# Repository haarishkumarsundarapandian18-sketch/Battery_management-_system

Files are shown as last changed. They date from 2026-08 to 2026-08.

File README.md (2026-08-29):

# Battery_management-_system

# CubeSat Battery Management System (BMS)

This project presents the complete development of a **Battery Management System (BMS) for a CubeSat**, starting from battery pack selection and modeling, followed by SoC estimation and BMS circuit development, and finally PCB design, manufacturing, assembly, and testing.

The project can be followed as a step-by-step workflow for developing a BMS from the initial battery requirements to a working hardware prototype.

## Project Workflow

### 1. Define Battery Requirements

Start by identifying the CubeSat's power requirements, including:

* Required battery voltage
* Required capacity
* Maximum and minimum load current
* Charging requirements
* Operating temperature range
* Expected discharge duration

These values are used to determine the required battery configuration and BMS specifications.

### 2. Design the Battery Pack

Select the appropriate battery cell based on the required voltage, capacity, discharge current, size, weight, and application requirements.

Determine the required **series (S) and parallel (P) configuration** and calculate:

* Pack voltage
* Pack capacity
* Maximum current
* Energy capacity

### 3. Build the Battery Model in MATLAB/Simulink

Create a battery model in **MATLAB/Simulink** using the selected cell characteristics.

Simulate the battery under different load conditions and observe:

* Battery voltage
* Current
* State of Charge (SoC)
* Discharge characteristics
* Battery response to changing loads

This step helps validate the battery configuration before moving to hardware development.

### 4. Implement SoC Estimation

Develop the **State of Charge estimation** model in MATLAB.

Use the battery voltage/current data and an appropriate estimation method to determine the remaining battery capacity during operation.

Test the SoC estimation model under different charge and discharge conditions and compare the estimated SoC with the expected battery behavior.

### 5. Develop the BMS Architecture

Define the BMS functions required for the battery pack.

The BMS architecture includes:

* Cell voltage monitoring
* Current sensing
* Temperature monitoring
* SoC estimation
* Battery protection
* Fault detection
* Control and communication

Define the required operating limits for each parameter.

### 6. Design the BMS Circuit

Select the required sensing, protection, control, and power-management components.

Develop the BMS schematic based on the defined architecture and connect:

* Voltage sensing circuits
* Current sensing circuit
* Temperature sensing
* Protection circuitry
* Power supply/regulation
* Controller/interface circuitry

Verify the circuit calculations and component ratings before PCB implementation.

### 7. Design the PCB in KiCad

Create the complete PCB using **KiCad**.

The process includes:

1. Creating the schematic
2. Assigning footprints
3. Creating the PCB layout
4. Placing components
5. Routing power and signal traces
6. Applying appropriate design rules
7. Checking clearances and track widths
8. Running Design Rule Checks (DRC)
9. Preparing the final PCB for manufacturing

Special attention is given to high-current paths, grounding, component placement, thermal considerations, and signal integrity.

### 8. PCB Manufacturing

Generate the required manufacturing files from KiCad and send the design for PCB fabrication.

After receiving the fabricated PCB:

* Inspect the board
* Verify footprints and connections
* Procure the required components
* Solder the components
* Inspect solder joints
* Check for shorts and incorrect connections

### 9. Hardware Testing

Power up the assembled BMS gradually and verify the individual sections before connecting the complete battery pack.

Test:

* Voltage sensing
* Current measurement
* Temperature measurement
* SoC estimation
* Protection functions
* Controller operation
* Communication/interface functions

Compare the measured hardware results with the MATLAB simulations and calculated values.

## Tools Used

* **MATLAB / Simulink** – Battery modeling and SoC estimation
* **KiCad** – Schematic capture and PCB design
* **PCB Fabrication & Assembly** – Hardware implementation
* **Battery Modeling** – Cell and pack characterization
* **BMS Design** – Monitoring and protection
* **Hardware Testing** – Validation of the developed system

## Overall Development Flow

**Battery Requirements → Battery Selection → Battery Pack Design → MATLAB Battery Modeling → SoC Estimation → BMS Architecture → Circuit Design → KiCad Schematic → PCB Layout → Manufacturing → Assembly → Testing & Validation**
# CubeSat Battery Management System (BMS)

This project presents the complete development of a **Battery Management System (BMS) for a CubeSat**, starting from battery pack selection and modeling, followed by SoC estimation and BMS circuit development, and finally PCB design, manufacturing, assembly, and testing.

The project can be followed as a step-by-step workflow for developing a BMS from the initial battery requirements to a working hardware prototype.

## Project Workflow

### 1. Define Battery Requirements

Start by identifying the CubeSat's power requirements, including:

* Required battery voltage
* Required capacity
* Maximum and minimum load current
* Charging requirements
* Operating temperature range
* Expected discharge duration

These values are used to determine the required battery configuration and BMS specifications.

### 2. Design the Battery Pack

Select the appropriate battery cell based on the required voltage, capacity, discharge current, size, weight, and application requirements.

Determine the required **series (S) and parallel (P) configuration** and calculate:

* Pack voltage
* Pack capacity
* Maximum current
* Energy capacity

### 3. Build the Battery Model in MATLAB/Simulink

Create a battery model in **MATLAB/Simulink** using the selected cell characteristics.

Simulate the battery under different load conditions and observe:

* Battery voltage
* Current
* State of Charge (SoC)
* Discharge characteristics
* Battery response to changing loads

This step helps validate the battery configuration before moving to hardware development.

### 4. Implement SoC Estimation

Develop the **State of Charge estimation** model in MATLAB.

Use the battery voltage/current data and an appropriate estimation method to determine the remaining battery capacity during operation.

Test the SoC estimation model under different charge and discharge conditions and compare the estimated SoC with the expected battery behavior.

### 5. Develop the BMS Architecture

Define the BMS functions required for the battery pack.

The BMS architecture includes:

* Cell voltage monitoring
* Current sensing
* Temperature monitoring
* SoC estimation
* Battery protection
* Fault detection
* Control and communication

Define the required operating limits for each parameter.

### 6. Design the BMS Circuit

Select the required sensing, protection, control, and power-management components.

Develop the BMS schematic based on the defined architecture and connect:

* Voltage sensing circuits
* Current sensing circuit
* Temperature sensing
* Protection circuitry
* Power supply/regulation
* Controller/interface circuitry

Verify the circuit calculations and component ratings before PCB implementation.

### 7. Design the PCB in KiCad

Create the complete PCB using **KiCad**.

The process includes:

1. Creating the schematic
2. Assigning footprints
3. Creating the PCB layout
4. Placing components
5. Routing power and signal traces
6. Applying appropriate design rules
7. Checking clearances and track widths
8. Running Design Rule Checks (DRC)
9. Preparing the final PCB for manufacturing

Special attention is given to high-current paths, grounding, component placement, thermal considerations, and signal integrity.

### 8. PCB Manufacturing

Generate the required manufacturing files from KiCad and send the design for PCB fabrication.

After receiving the fabricated PCB:

* Inspect the board
* Verify footprints and connections
* Procure the required components
* Solder the components
* Inspect solder joints
* Check for shorts and incorrect connections

### 9. Hardware Testing

Power up the assembled BMS gradually and verify the individual sections before connecting the complete battery pack.

Test:

* Voltage sensing
* Current measurement
* Temperature measurement
* SoC estimation
* Protection functions
* Controller operation
* Communication/interface functions

Compare the measured hardware results with the MATLAB simulations and calculated values.

## Tools Used

* **MATLAB / Simulink** – Battery modeling and SoC estimation
* **KiCad** – Schematic capture and PCB design
* **PCB Fabrication & Assembly** – Hardware implementation
* **Battery Modeling** – Cell and pack characterization
* **BMS Design** – Monitoring and protection
* **Hardware Testing** – Validation of the developed system

## Overall Development Flow

**Battery Requirements → Battery Selection → Battery Pack Design → MATLAB Battery Modeling → SoC Estimation → BMS Architecture → Circuit Design → KiCad Schematic → PCB Layout → Manufacturing → Assembly → Testing & Validation**

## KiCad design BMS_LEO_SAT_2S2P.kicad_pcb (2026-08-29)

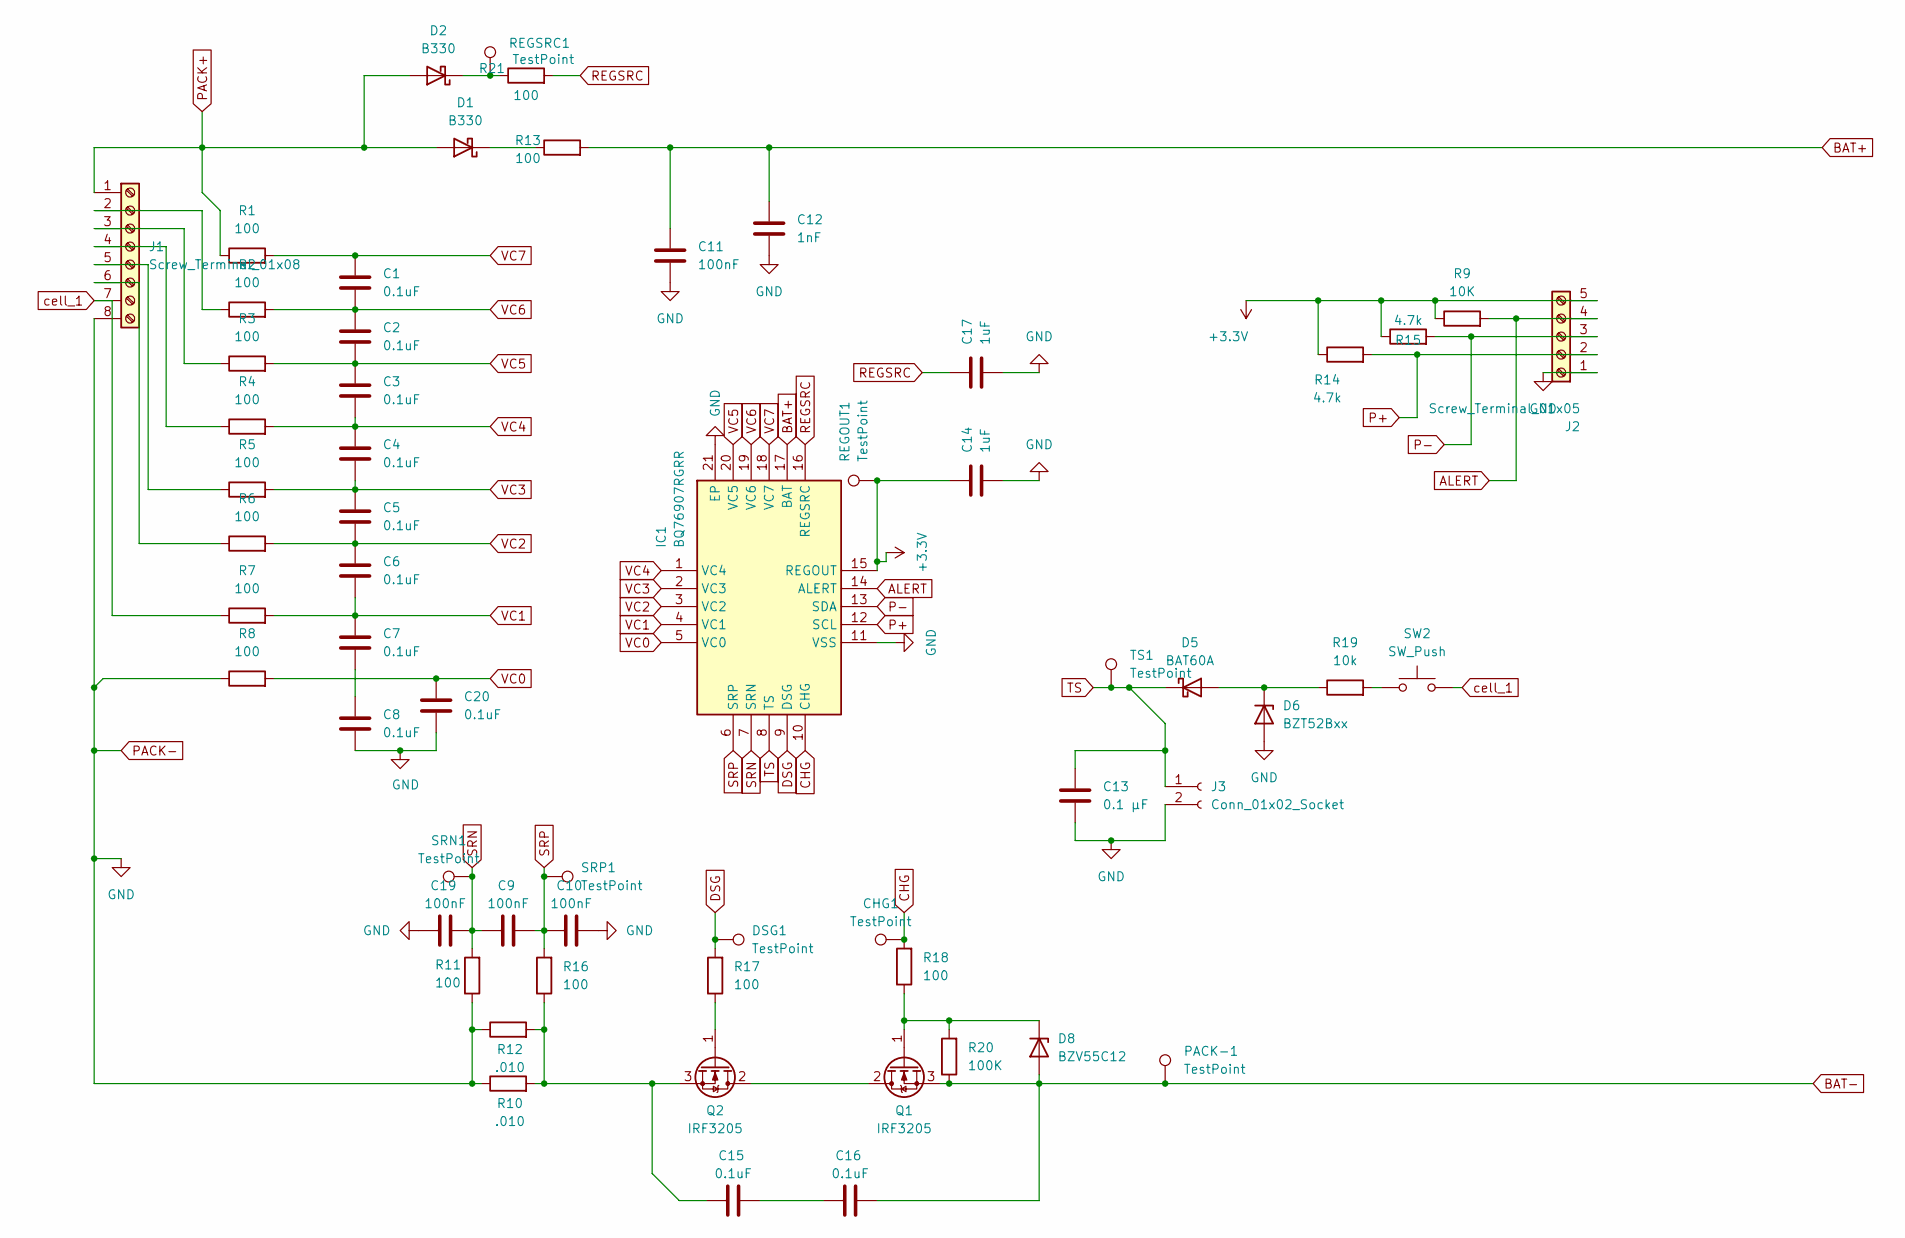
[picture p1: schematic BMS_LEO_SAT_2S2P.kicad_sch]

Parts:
C1, C2, C3, C4, C5, C6, C7, C8, C15, C16, C20: 0.1uF; C_0603_1608Metric_Pad1.08x0.95mm_HandSolder
C9, C10, C11, C19: 100nF; C_0603_1608Metric_Pad1.08x0.95mm_HandSolder
C12: 1nF; C_0603_1608Metric_Pad1.08x0.95mm_HandSolder
C13: 0.1 µF; C_0603_1608Metric_Pad1.08x0.95mm_HandSolder
C14, C17: 1uF; C_0603_1608Metric_Pad1.08x0.95mm_HandSolder
CHG1: TestPoint; PinHeader_1x01_P1.00mm_Vertical
D1, D2: B330; D_SMC
D5: BAT60A; D_SOD-323
D6: BZT52Bxx; D_SOD-123F
D8: BZV55C12; D_MiniMELF
DSG1: TestPoint; PinHeader_1x01_P1.00mm_Vertical
IC1: BQ76907RGRR; QFN50P350X350X100-21N-D; Manufacturer_Part_Number BQ76907RGRR; Mouser Part Number 595-BQ76907RGRR
J1: Screw_Terminal_01x08; TerminalBlock_Phoenix_MPT-0,5-8-2.54_1x08_P2.54mm_Horizontal
J2: Screw_Terminal_01x05; TerminalBlock_Phoenix_MPT-0,5-5-2.54_1x05_P2.54mm_Horizontal
J3: Conn_01x02_Socket; PinSocket_1x02_P2.00mm_Vertical
PACK-1: TestPoint; PinHeader_1x01_P1.00mm_Vertical
Q1, Q2: IRF3205; TO-220-3_Vertical
R1, R2, R3, R4, R5, R6, R7, R8, R11, R13, R16, R17, R18, R21: 100; R_0603_1608Metric_Pad0.98x0.95mm_HandSolder
R9: 10K; R_0603_1608Metric_Pad0.98x0.95mm_HandSolder
R10: .010; R_2512_6332Metric_Pad1.40x3.35mm_HandSolder
R12: .010; R_0603_1608Metric_Pad0.98x0.95mm_HandSolder
R14, R15: 4.7k; R_0603_1608Metric_Pad0.98x0.95mm_HandSolder
R19: 10k; R_0603_1608Metric_Pad0.98x0.95mm_HandSolder
R20: 100K; R_0603_1608Metric_Pad0.98x0.95mm_HandSolder
REGOUT1: TestPoint; PinHeader_1x01_P1.00mm_Vertical
REGSRC1: TestPoint; PinHeader_1x01_P1.00mm_Vertical
SRN1: TestPoint; PinHeader_1x01_P1.00mm_Vertical
SRP1: TestPoint; PinHeader_1x01_P1.00mm_Vertical
SW2: SW_Push; SW_SPST_CK_RS282G05A3
TS1: TestPoint; PinHeader_1x01_P1.00mm_Vertical

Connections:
+3.3V: C14.1, IC1.15 (REGOUT), J2.5, R9.1, R14.1, R15.1, REGOUT1.1
ALERT: IC1.14 (ALERT), J2.4, R9.2
BAT+: C11.1, C12.1, IC1.17 (BAT), R13.2
BAT-: C16.2, D8.2 (A), PACK-1.1, Q1.3 (S), R20.1
CHG: CHG1.1, IC1.10 (CHG), R18.2
DSG: DSG1.1, IC1.9 (DSG), R17.2
unnamed: C7.2, C8.1
unnamed: C15.2, C16.1
unnamed: D1.1 (K), R13.1
unnamed: D2.1 (K), R21.1, REGSRC1.1
unnamed: D5.2 (A), D6.1 (K), R19.1
unnamed: D8.1 (K), Q1.1 (G), R18.1, R20.2
unnamed: J1.2, R2.1
unnamed: J1.3, R3.1
unnamed: J1.4, R4.1
unnamed: J1.5, R5.1
unnamed: J1.6, R6.1
unnamed: Q1.2 (D), Q2.2 (D)
unnamed: Q2.1 (G), R17.1
unnamed: C15.1, Q2.3 (S), R10.2, R12.2, R16.1
unnamed: R19.2, SW2.1
P+: IC1.12 (SCL), J2.2, R14.2
P-: IC1.13 (SDA), J2.3, R15.2
PACK+: D1.2 (A), D2.2 (A), J1.1, R1.1
PACK-: C8.2, C10.2, C11.2, C12.2, C13.2, C14.2, C17.2, C19.1, C20.2, D6.2 (A), IC1.11 (VSS), IC1.21 (EP), J1.8, J2.1, J3.2, R8.1, R10.1, R11.1, R12.1
REGSRC: C17.1, IC1.16 (REGSRC), R21.2
SRN: C9.1, C19.2, IC1.7 (SRN), R11.2, SRN1.1
SRP: C9.2, C10.1, IC1.6 (SRP), R16.2, SRP1.1
TS: C13.1, D5.1 (K), IC1.8 (TS), J3.1, TS1.1
VC0: C20.1, IC1.5 (VC0), R8.2
VC1: C6.2, C7.1, IC1.4 (VC1), R7.2
VC2: C5.2, C6.1, IC1.3 (VC2), R6.2
VC3: C4.2, C5.1, IC1.2 (VC3), R5.2
VC4: C3.2, C4.1, IC1.1 (VC4), R4.2
VC5: C2.2, C3.1, IC1.20 (VC5), R3.2
VC6: C1.2, C2.1, IC1.19 (VC6), R2.2
VC7: C1.1, IC1.18 (VC7), R1.2
cell_1: J1.7, R7.1, SW2.2

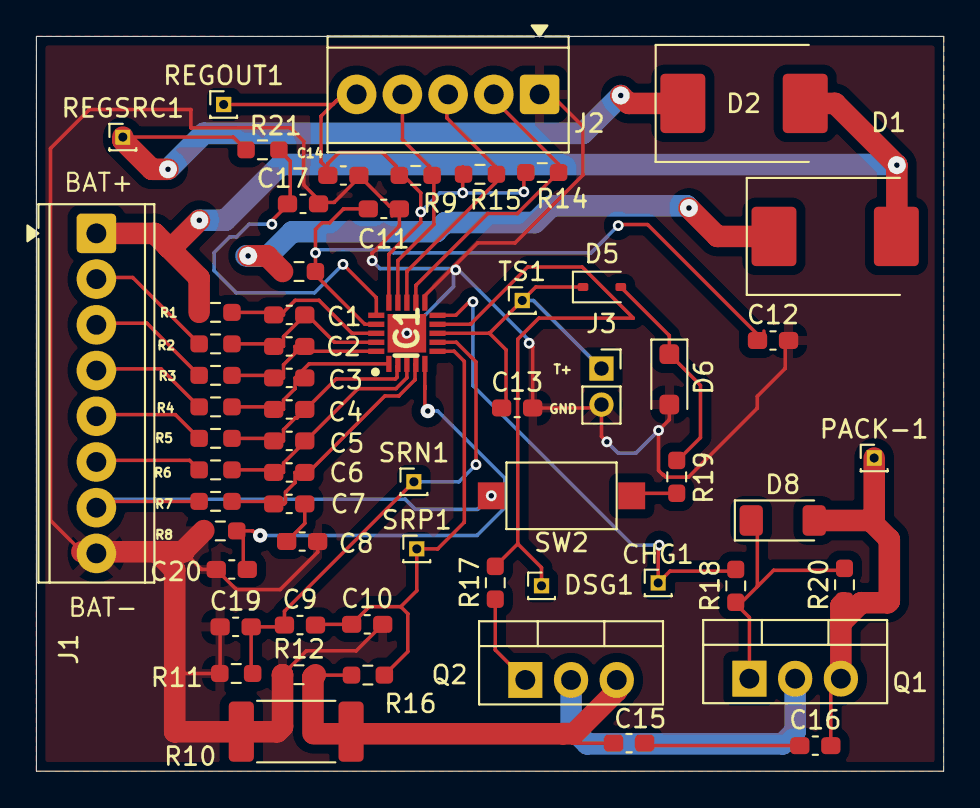
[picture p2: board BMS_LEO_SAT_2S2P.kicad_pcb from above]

Board: 2 copper layers, 50.4 x 40.8 mm, 60 parts (0 on the bottom side), 38 nets.

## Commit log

2026-08-29 Enhance README with project details for BMS
    Added detailed project description for the Battery Management System, outlining the development process, simulation models, BMS architecture, and hardware implementation.
2026-08-29 Revise README with detailed project workflow
    Updated the README to provide a detailed project workflow for the CubeSat Battery Management System (BMS), including steps from defining battery requirements to hardware testing.
